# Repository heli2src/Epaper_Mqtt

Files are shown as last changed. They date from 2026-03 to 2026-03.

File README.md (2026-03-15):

# Epaper_Mqtt

Displaying icons and measured values on an e-paper display:

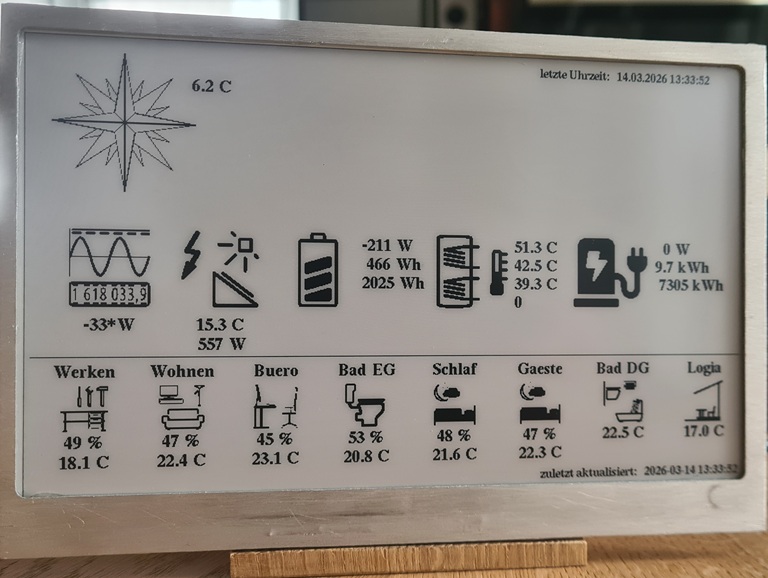
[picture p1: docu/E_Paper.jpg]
Image of the e-paper displaying icons and measurement values Displaying icons and measurement values on an e-paper display


The Raspberry Pi Pico 2W uses its SPI interface to control a 7.5-inch EPD (Electronic Paper Display) with a resolution of 800 x 480 pixels. I am using a two-colour EPD with black and red.

The icons and data to be displayed can be flexibly configured via the [config.py](https://github.com/heli2src/Epaper_Mqtt/blob/main/config.py) file. 
The Pico receives the measurement values via Wi-Fi from a central MQTT broker.
Upon startup, the dictionary TOPICS = {...} in [config.py](https://github.com/heli2src/Epaper_Mqtt/blob/main/config.py) is evaluated and the corresponding topics are subscribed to at the broker. The received values are formatted and stored as a string in a variable. 

The icons and text to be displayed are defined in the dictionary CONTENT={...}. 

The first three variables in config.py must be set to the Wi-Fi network being used:

  - SERVER = "xxx.xxx.xxx.xxx"    # e.q. "192.168.145.45"
  
  - WlPw = "your wlan password"   
  
  - WlSsid = "name from your wlan"

## Setting up the TOPICS dictionary and subscribing to a topic:

Using the MQTT Explorer (https://mqtt-explorer.com/), you can view all topics and messages from your MQTT broker. 
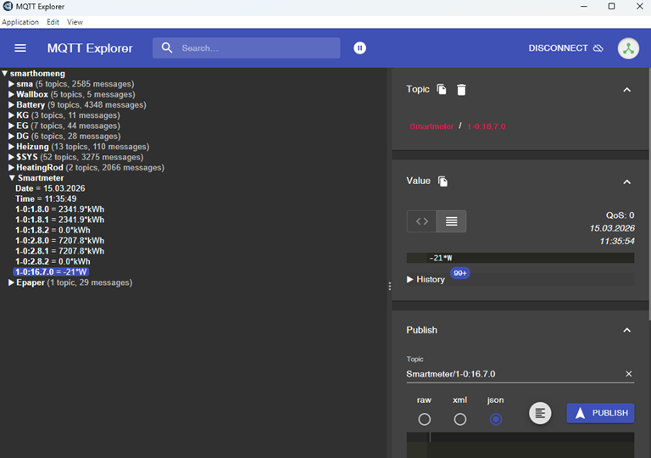
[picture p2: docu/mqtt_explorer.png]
Image of the MQTT Explorer Display of the topic Smartmeter/1-0:16.7.0


For example, the reading from the smart meter, which indicates the house’s current power consumption, should be subscribed to from channel 1-0:16-7.0 and stored in the variable `current_power`. Furthermore, the temperature of the heating system’s collector should be stored in the variable `hz_koll`.
```
   TOPICS = {
          "Smartmeter": {
              "1-0:16.7.0": ["current_power"]
              },
        "Heizung": {         
              "Kollektor": {
                  "Temperatur": ["hz_koll", "4.1f", " C"],
                  },              
   }
```
The temperature of the collector is displayed as a floating-point number with one decimal place, with the unit ‘C’ appended at the end. The measured value is then stored as a string in the variable ‘hz_koll’.

## Structure of the CONTENT dictionary for displaying icons and text:
  - "text": {} displays text using the specified font at a specific position (x, y).
  - "tiles": {} displays an icon; text can also be displayed to the right and below the icon.
  - "lines": {} displays lines to separate sections.

For example, the measured values `current_power` and `hz_koll` should be displayed with an icon and their respective values:
   ```
   sxroom = 20
   line2 = 180

   CONTENT = {
      "tiles": {
            "S": {                                           # Solar, if len("E") < 2 than no name will be placed
            "c": ["measure_photovoltaic_inst", tfont21],     # c = content [Name des Icons, Font]
            "p": [sxroom + 115, line2],                      # p = placement (x, y)
            "v": ["hz_koll"]},                               # v = Text vertical placement under the icon, h = horizontal
   ```
The icons must be saved as “Portable Bitmap” files in the “images” directory. To this end, I have written a converter at https://github.com/heli2src/svg2pbm that converts single-colour SVG files into the Portable Bitmap format. Relevant SVG icons can, for example, be obtained from the [smartVISU](https://www.smartvisu.de/) project on [GitHub](https://github.com/Martin-Gleiss/smartvisu/tree/master/icons/sw). Using the converter, they can then be converted into any size.

Due to the large 800 x 480-pixel display, the icons and the various fonts, memory usage is very high, meaning it only runs on a Raspberry Pi Pico 2W with the [RP2350](https://de.wikipedia.org/wiki/RP2350). The [RP2040](https://de.wikipedia.org/wiki/RP2040) has too little internal RAM for this. 

When I was writing the software for the display, MicroPython version 1.25 was the latest available. However, I couldn’t get the power-saving mode `machine.lightsleep(20000)` to work with that version. But as my display is connected directly to the KNX power supply via a voltage converter, I wasn’t too concerned about the average current draw of 25 mA at first.
However, if the e-paper is to be battery-powered, this needs to be improved. 

The Python code is available on my [Github](https://github.com/heli2src/Epaper_Mqtt) page. The project should run once you’ve adjusted the [config.py](https://github.com/heli2src/Epaper_Mqtt/blob/main/config.py). All required libraries are present in the directory; the externally used library versions are from December 2024. The [Peter Hinch Nano-gui](https://github.com/peterhinch/micropython-nano-gui) library is used for the GUI, and the MQTT-Simple version of [miccropython-lib](https://github.com/micropython/micropython-lib/tree/master/micropython/umqtt.simple) is used.

The GitHub section also contains the [CAD files](https://github.com/heli2src/Epaper_Mqtt/tree/main/cad) for the aluminium frame and the electronics box, suitable for milling or 3D printing.

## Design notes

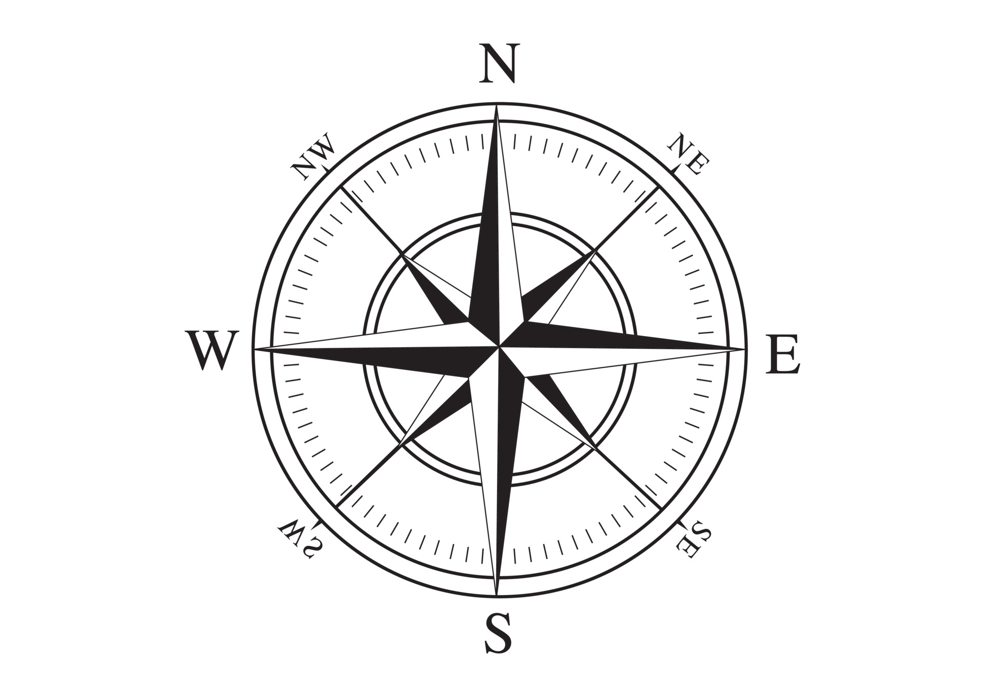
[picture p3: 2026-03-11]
images_inwork/vecteezy_black-and-white-nautical-compass-isolated-on-white_8143436.jpg

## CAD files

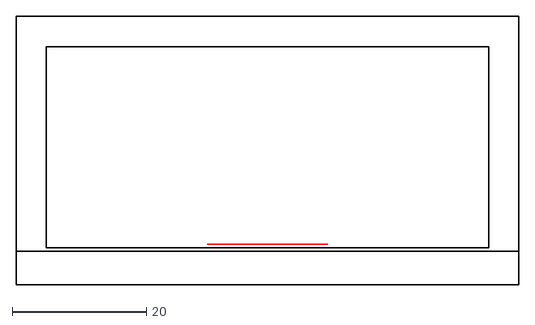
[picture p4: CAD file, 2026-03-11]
cad/box.dxf
75.0 x 40.0

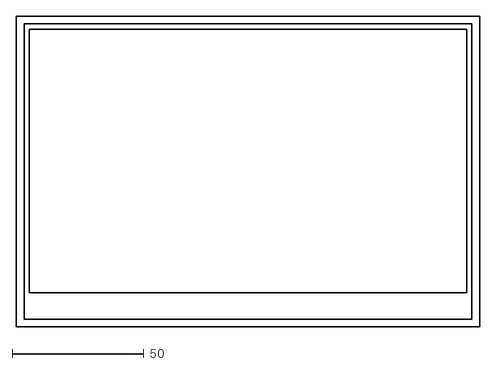
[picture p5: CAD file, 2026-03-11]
cad/CAM/rahmen-display.dxf
176.0 x 118.0

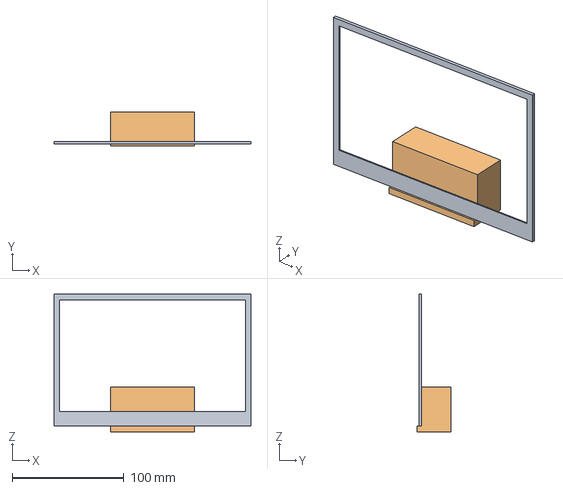
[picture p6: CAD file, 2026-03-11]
cad/EPaper-Gehaeuse.FCStd
176.0 x 30.0 x 123.0 mm
Rahmen
Elektronik-Box

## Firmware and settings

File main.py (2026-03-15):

# Released under the MIT license see LICENSE

# without deepsleep ~57-65mA

import os
import gc
import time
import framebuf
import machine
from time import sleep
from color_setup import ssd
from color_setup import ssdred
from update import Update
import config
import re
import gc

from gui.widgets.dial import Dial

from wlanmqtt import WlanMqtt
from tiles import Tiles

def time2str(t):
    return f'{t[2]:02d}.{t[1]:02d}.{t[0]:04d} {t[4]:02d}:{t[5]:02d}:{t[6]:02d}'

led = machine.Pin('LED', machine.Pin.OUT, value=1)
ssdred.fill(0)
ssd.fill(0)          # auf White setzen

tiles = Tiles(config.CONTENT)
updates = Update(led, state_topic=config.Topic)
# ssdred = None
rtc =machine.RTC()
tiles.printf(f'{time2str(rtc.datetime())}\Start Wlan connection:', ssd)
ssdred.show()
ssd.show()
gc.collect()

startuploop = True

while True:
    try:
        mqttclient = WlanMqtt(config.SERVER, wlSsid=config.WlSsid, wlPw=config.WlPw, led=led)
        mqttclient.init(config.TOPICS, f"{config.Topic},disconnect")
        # mqttclient.init(config.TOPICS,)    
        
        starttime = time.time()
        print(f"collect messages for {config.mqtt_waittime}s")    
        while time.time()-starttime < config.mqtt_waittime:           # collect mqtt messages
            time.sleep(1)
            mqttclient.mqtt.publish(config.Topic, b'collect')        
            while mqttclient.mqtt.check_msg():
                mqttclient.mqtt.wait_msg()
        print("   -> collecting done")

        while startuploop:                                            # set time at startup
            while mqttclient.mqtt.check_msg():
                mqttclient.mqtt.wait_msg()
            if mqttclient.mqtt_result['sma_time'] != 0:
                startuploop = False
            if not startuploop:
                regex = re.compile('[- :]')
                dt = [int(s) for s in regex.split(mqttclient.mqtt_result['sma_time'])]
                dt.insert(3, 0)       # add day of the week
                dt.append(0)            
                rtc.datetime(tuple(dt))
        
        time.sleep(1)
        if "update" in mqttclient.mqtt_result and mqttclient.mqtt_result['update'] != 'run':
            updates.do(mqttclient, mqttclient.mqtt_result)   
        else:
            print('no update found')

        mqttclient.mqtt.publish(config.Topic, b'run')
        time.sleep(1)

        if True:
            mqttclient.mqtt.publish(config.Topic, b'sleep')      # wlan modul disabled    
            time.sleep(1)
            mqttclient.disconnect()
            mqttclient.mqtt_result['last_time'] = time2str(rtc.datetime())
            tiles.dvar = mqttclient.mqtt_result                 # get all variables from mqtt
            ssd.init()
            led.off()                
            tiles.tiles2display(ssd, ssdred)                    # calculate the titles
            tiles.text2display(ssd, ssdred)
            tiles.lines2display(ssd)
            ssdred.show()
            ssd.show()
            machine.freq(20_000_000)        
            ssd.sleep()
            gc.collect()
            print(f"update done {mqttclient.mqtt_result['last_time']}")
            print(f"  next update: {config.epaper_update}s")        

            # TODO enable sleep mode for the RP2040
            time.sleep(config.epaper_update)
            #machine.lightsleep(20000)     # does not work :-( with MicroPython > v1.23
            machine.freq(125_000_000)
        else:
            break
    except Exception as ex:
        ssd.init()
        tiles.printf(f'{time2str(rtc.datetime())}\nError: {ex}', ssdred)
        ssdred.show()
        ssd.show()
        
        ssd.sleep()
        for i in range(config.epaper_update):
            for j in range (0, 4):
                led.toggle()
                sleep(0.25)

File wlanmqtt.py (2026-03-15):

# Released under the MIT license see LICENSE

import binascii
import machine
import network
import rp2
import utime as time
import urequests as requests
from lib.umqtt.simple import MQTTClient         # https://github.com/micropython/micropython-lib/blob/master/micropython/umqtt.simple/umqtt/simple.py

rp2.country('DE')


class WlanMqtt():
    """class for connecting to a WLAN MQTT Broker.

    Status led is switched on during connection setup, when connection is established it goes out.
    Collects all messages in self.mqtt_result.
    The messages themselves are subscribed to by a json file
    Example in the __main__ area
    Format of the json file:
      {"sma": {
            "P_AC": ["sma_solar", "5.1f"],
            "STIME": ["sma_time", ""]
            },
        "Smartmeter": {
              "1-0:16.7.0": ["current_power", [:-2]]
              },
              
    --> subscribed for:
        "sma/P_AC" and assigns the received messages to the variable self.mqtt_result["sma_solar"]
        "sma/STIME" and assigns the received messages to the variable self.mqtt_result["sma_time"]
        "Smartmeter/1-0:16.7.0" and assigns the received messages to the variable self.mqtt_result["current_power"]       
    """

    def __init__(self, server, wlSsid, wlPw, led, clientid=None):
        """
        Initialisation for the WLAN MQTT client.

        server : str
            ip Adresse from the broker, e.q = "192.178.158.22"
        wlPw : str
            password for your wlan Server
        wlSsid: str
            name from the Server
        """
        self.led = led    # Status LED
        self.mqtt_result = {}
        self.msg = ""
        while True:
            status = self._wlanConnect(wlSsid, wlPw)
            if status >= 3:
                break
            print('Restart Wlan connection')
        print('Start Mqtt connection')
        clientid = binascii.hexlify(machine.unique_id()) if clientid is None else clientid
        self.mqtt = MQTTClient(clientid, server)
        print(f"Client {clientid} connected to {server}")

    def init(self, topics, lastwill=None):
        """
        Set the callback.

        Subscribed messages will be delivered to this callback.
        Results are stored to mqtt_result.

        topics: dict
            e.q. {"sma": {"P_AC": ["sma_solar", int]}    topic = sma.P_AC,
                                                         value is an integer, saved to mqtt_result[sma_solar]
        """
        def topicstr(subtopic, mqttstr=None):
            for ssubtopic in subtopic.keys():
                if type(subtopic[ssubtopic]) is list:
                    print(f" subscribe to {mqttstr}/{ssubtopic}, set mqtt_result['{subtopic[ssubtopic][0]}]")
                    self.mqtt_result[subtopic[ssubtopic][0]] = 0
                    self.mqtt.subscribe(f"{mqttstr}/{ssubtopic}")
                else:
                    mqttstr = topicstr(subtopic[ssubtopic], f'{mqttstr}/{ssubtopic}' if mqttstr is not None else ssubtopic)
            return mqttstr[:mqttstr.find('/')] if mqttstr is not None and mqttstr.find('/') > 0 else None

        self.topics = topics
        self.mqtt.set_callback(self._sub_callback)
        if lastwill is not None:
            lastwill = lastwill.split(',')
            self.mqtt.set_last_will(lastwill[0], lastwill[1], retain=False, qos=0)
        self.mqtt.connect()        
        topicstr(topics)
        
    def reconnect(self):
        print('Failed to connect to MQTT broker, Reconnecting...' % (server))
        time.sleep(5)
        mqtt.reconnect()    
        
    def disconnect(self):
        self.mqtt.disconnect()
        self.wlan.disconnect()
        self.wlan.deinit()

    @property
    def status(self):
        if self.wlan.isconnected():
            return self.wlan.status()
        else:
            return -1

    def _sub_callback(self, topic, msg):
        topic = topic.decode('utf-8').split('/')
        msg = msg.decode('utf-8')
        searchtopic = self.topics
        index = 0
        while index < len(topic):        # search for the corresponding variable name
            if topic[index] in searchtopic.keys():
                searchtopic = searchtopic[topic[index]]
                index += 1
            else:
                print('Error: topic {topic} not found in topics')
                return
        msg = f"{float(msg):{searchtopic[1]}}" if len(searchtopic)>1 else msg       # format
        msg = f"{msg}{searchtopic[2]}" if len(searchtopic)>2 else msg               # add post message
        self.mqtt_result[searchtopic[0]] = msg

    def _wlanConnect(self, wlSsid, wlPw):
        """ Create the WLAN-Connection."""
        wlan = network.WLAN(network.STA_IF)
        if not wlan.isconnected():
            print('WLAN setup connection')
            wlan.deinit()            
            wlan.active(True)
            print('WLAN enabled')
            time.sleep(2)
            wlan.connect(wlSsid, wlPw)
            for i in range(10):
                status = wlan.status()
                if status < 0 or status >= 3:
                    break
                self.led.toggle()
                print('->', status)
                time.sleep(0.5)
        if wlan.isconnected():
            print('WLAN connection ok')
            self.led.on()
            status = wlan.status()
            print('WLAN state:', status)
            netConfig = wlan.ifconfig()
            print('IPv4-Adresse:', netConfig[0], '/', netConfig[1])
            print('Standard-Gateway:', netConfig[2])
            print('DNS-Server:', netConfig[3])
            time.sleep(3)
            self.led.off()
            self.wlan = wlan
        else:
            print('No WLAN connection')
            self.led.off()
            status = wlan.status()
            print('WLAN state:', status)
        return status


if __name__ == "__main__":
    from config import SERVER, WlSsid, WlPw
    from config import TOPICS

    led = machine.Pin('LED', machine.Pin.OUT, value=0)
    client = WlanMqtt(SERVER, wlSsid=WlSsid, wlPw=WlPw, led=led)
    topics = {"sma": {"P_AC": ["solar", int]}}           # get Topic "sma\P_AC" This should be change to your Topic
    topics = TOPICS
    client.init(topics)
    try:
        lasttime = time.time() - 9
        while 1:
            # micropython.mem_info()
            client.mqtt.wait_msg()
            if (time.time() - lasttime) > 10:
                print(client.mqtt_result)                  # all received topics are in mqtt_result
                lasttime = time.time()                      
    finally:
        client.mqtt.disconnect()
